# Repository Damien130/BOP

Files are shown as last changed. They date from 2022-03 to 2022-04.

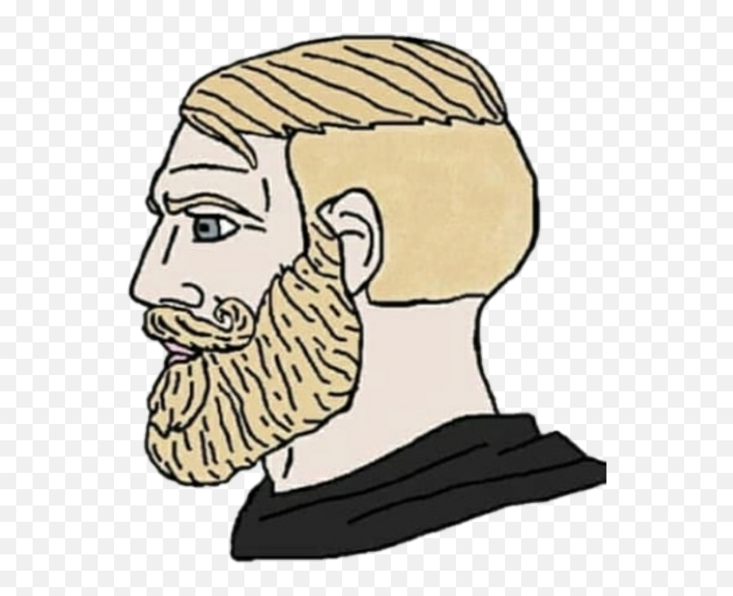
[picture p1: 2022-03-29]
pcb/Chad.png

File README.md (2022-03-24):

	Welcome to Chad
	Brought to you by
	ECE1895
⠀⠀⠘⡀⠀⠀⠀⠀⠀⠀⠀⠀⠀⠀⠀⠀⠀⠀⠀⠀⠀⠀⠀⠀⠀⠀⡜⠀⠀⠀
⠀⠀⠀⠑⡀⠀⠀⠀⠀⠀⠀⠀⠀⠀⠀⠀⠀⠀⠀⠀⠀⠀⠀⠀⠀⡔⠁⠀⠀⠀
⠀⠀⠀⠀⠈⠢⢄⠀⠀⠀⠀⠀⠀⠀⠀⠀⠀⠀⠀⠀⠀⠀⣀⠴⠊⠀⠀⠀⠀⠀
⠀⠀⠀⠀⠀⠀⠀⢸⠀⠀⠀⢀⣀⣀⣀⣀⣀⡀⠤⠄⠒⠈⠀⠀⠀⠀⠀⠀⠀⠀
⠀⠀⠀⠀⠀⠀⠀⠘⣀⠄⠊⠁⠀⠀⠀⠀⠀⠀⠀⠀⠀⠀⠀⠀⠀⠀⠀⠀⠀⠀
⠀
⣿⣿⣿⣿⣿⣿⣿⣿⡿⠿⠛⠛⠛⠋⠉⠈⠉⠉⠉⠉⠛⠻⢿⣿⣿⣿⣿⣿⣿⣿
⣿⣿⣿⣿⣿⡿⠋⠁⠀⠀⠀⠀⠀⠀⠀⠀⠀⠀⠀⠀⠀⠀⠀⠉⠛⢿⣿⣿⣿⣿
⣿⣿⣿⣿⡏⣀⠀⠀⠀⠀⠀⠀⠀⣀⣤⣤⣤⣄⡀⠀⠀⠀⠀⠀⠀⠀⠙⢿⣿⣿
⣿⣿⣿⢏⣴⣿⣷⠀⠀⠀⠀⠀⢾⣿⣿⣿⣿⣿⣿⡆⠀⠀⠀⠀⠀⠀⠀⠈⣿⣿
⣿⣿⣟⣾⣿⡟⠁⠀⠀⠀⠀⠀⢀⣾⣿⣿⣿⣿⣿⣷⢢⠀⠀⠀⠀⠀⠀⠀⢸⣿
⣿⣿⣿⣿⣟⠀⡴⠄⠀⠀⠀⠀⠀⠀⠙⠻⣿⣿⣿⣿⣷⣄⠀⠀⠀⠀⠀⠀⠀⣿
⣿⣿⣿⠟⠻⠀⠀⠀⠀⠀⠀⠀⠀⠀⠀⠶⢴⣿⣿⣿⣿⣿⣧⠀⠀⠀⠀⠀⠀⣿
⣿⣁⡀⠀⠀⢰⢠⣦⠀⠀⠀⠀⠀⠀⠀⠀⢀⣼⣿⣿⣿⣿⣿⡄⠀⣴⣶⣿⡄⣿
⣿⡋⠀⠀⠀⠎⢸⣿⡆⠀⠀⠀⠀⠀⠀⣴⣿⣿⣿⣿⣿⣿⣿⠗⢘⣿⣟⠛⠿⣼
⣿⣿⠋⢀⡌⢰⣿⡿⢿⡀⠀⠀⠀⠀⠀⠙⠿⣿⣿⣿⣿⣿⡇⠀⢸⣿⣿⣧⢀⣼
⣿⣿⣷⢻⠄⠘⠛⠋⠛⠃⠀⠀⠀⠀⠀⢿⣧⠈⠉⠙⠛⠋⠀⠀⠀⣿⣿⣿⣿⣿
⣿⣿⣧⠀⠈⢸⠀⠀⠀⠀⠀⠀⠀⠀⠀⠀⠟⠀⠀⠀⠀⢀⢃⠀⠀⢸⣿⣿⣿⣿
⣿⣿⡿⠀⠴⢗⣠⣤⣴⡶⠶⠖⠀⠀⠀⠀⠀⠀⠀⠀⠀⠀⠀⣀⡸⠀⣿⣿⣿⣿
⣿⣿⣿⡀⢠⣾⣿⠏⠀⠠⠀⠀⠀⠀⠀⠀⠀⠀⠀⠀⠀⠀⠀⠛⠉⠀⣿⣿⣿⣿
⣿⣿⣿⣧⠈⢹⡇⠀⠀⠀⠀⠀⠀⠀⠀⠀⠀⠀⠀⠀⠀⠀⠀⠀⠀⣰⣿⣿⣿⣿
⣿⣿⣿⣿⡄⠈⠃⠀⠀⠀⠀⠀⠀⠀⠀⠀⠀⠀⠀⠀⠀⢀⣠⣴⣾⣿⣿⣿⣿⣿
⣿⣿⣿⣿⣧⡀⠀⠀⠀⠀⠀⠀⠀⠀⠀⠀⠀⠀⢀⣠⣾⣿⣿⣿⣿⣿⣿⣿⣿⣿
⣿⣿⣿⣿⣷⠀⠀⠀⠀⠀⠀⠀⠀⠀⠀⠀⢀⣴⣿⣿⣿⣿⣿⣿⣿⣿⣿⣿⣿⣿
⣿⣿⣿⣿⣿⣦⣄⣀⣀⣀⣀⠀⠀⠀⠀⠘⣿⣿⣿⣿⣿⣿⣿⣿⣿⣿⣿⣿⣿⣿
⣿⣿⣿⣿⣿⣿⣿⣿⣿⣿⣿⣷⡄⠀⠀⠀⣿⣿⣿⣿⣿⣿⣿⣿⣿⣿⣿⣿⣿⣿
⣿⣿⣿⣿⣿⣿⣿⣿⣿⣿⣿⣿⣧⠀⠀⠀⠙⣿⣿⡟⢻⣿⣿⣿⣿⣿⣿⣿⣿⣿
⣿⣿⣿⣿⣿⣿⣿⣿⣿⣿⣿⣿⠇⠀⠁⠀⠀⠹⣿⠃⠀⣿⣿⣿⣿⣿⣿⣿⣿⣿
⣿⣿⣿⣿⣿⣿⣿⣿⡿⠛⣿⣿⠀⠀⠀⠀⠀⠀⠀⠀⢐⣿⣿⣿⣿⣿⣿⣿⣿⣿
⣿⣿⣿⣿⠿⠛⠉⠉⠁⠀⢻⣿⡇⠀⠀⠀⠀⠀⠀⢀⠈⣿⣿⡿⠉⠛⠛⠛⠉⠉
⣿⡿⠋⠁⠀⠀⢀⣀⣠⡴⣸⣿⣇⡄⠀⠀⠀⠀⢀⡿⠄⠙⠛⠀⣀⣠⣤⣤⠄

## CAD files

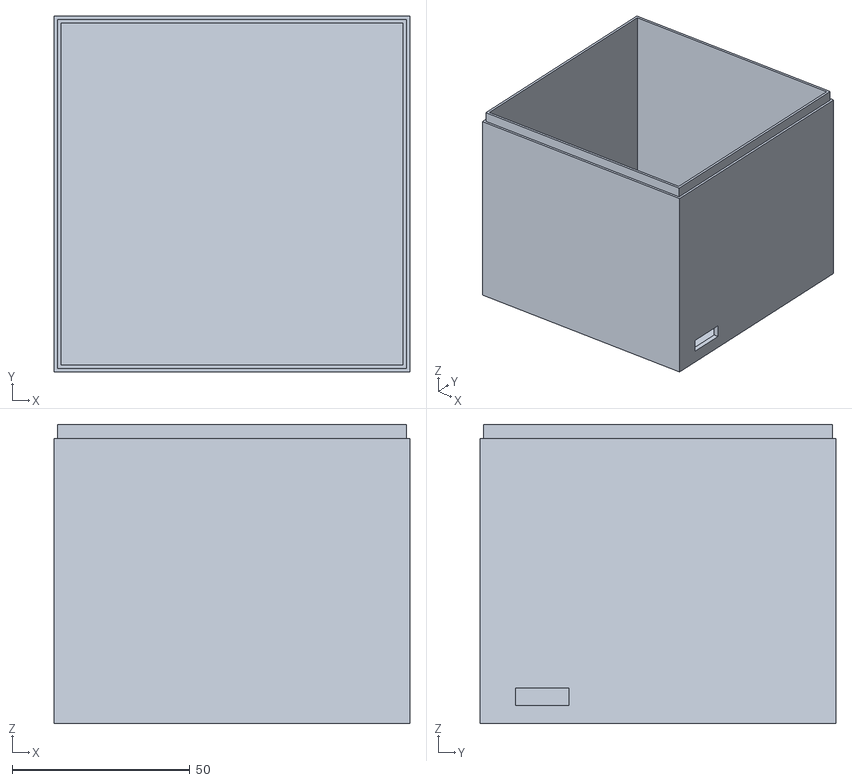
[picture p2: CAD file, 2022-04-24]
enclosure/Bop-it3 Box.stl
100.0 x 100.0 x 84.0

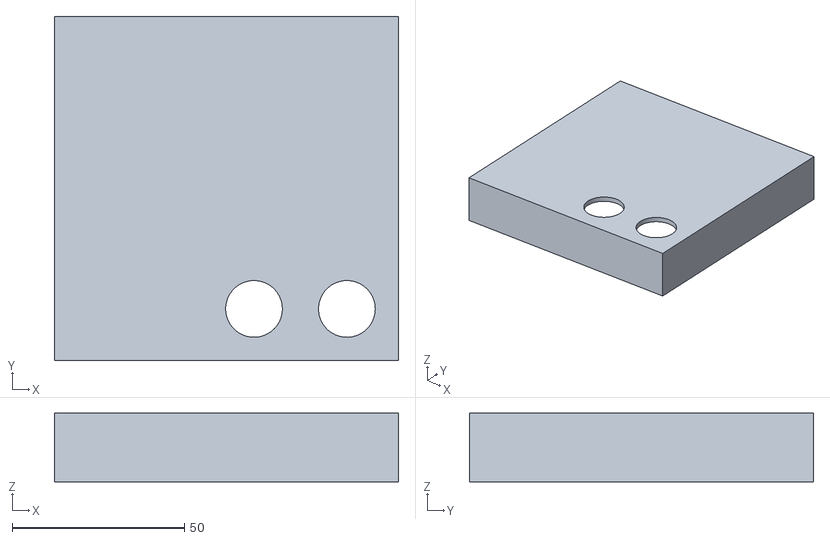
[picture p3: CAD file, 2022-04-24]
enclosure/Bop-it3 Lid.stl
100.0 x 100.0 x 20.0

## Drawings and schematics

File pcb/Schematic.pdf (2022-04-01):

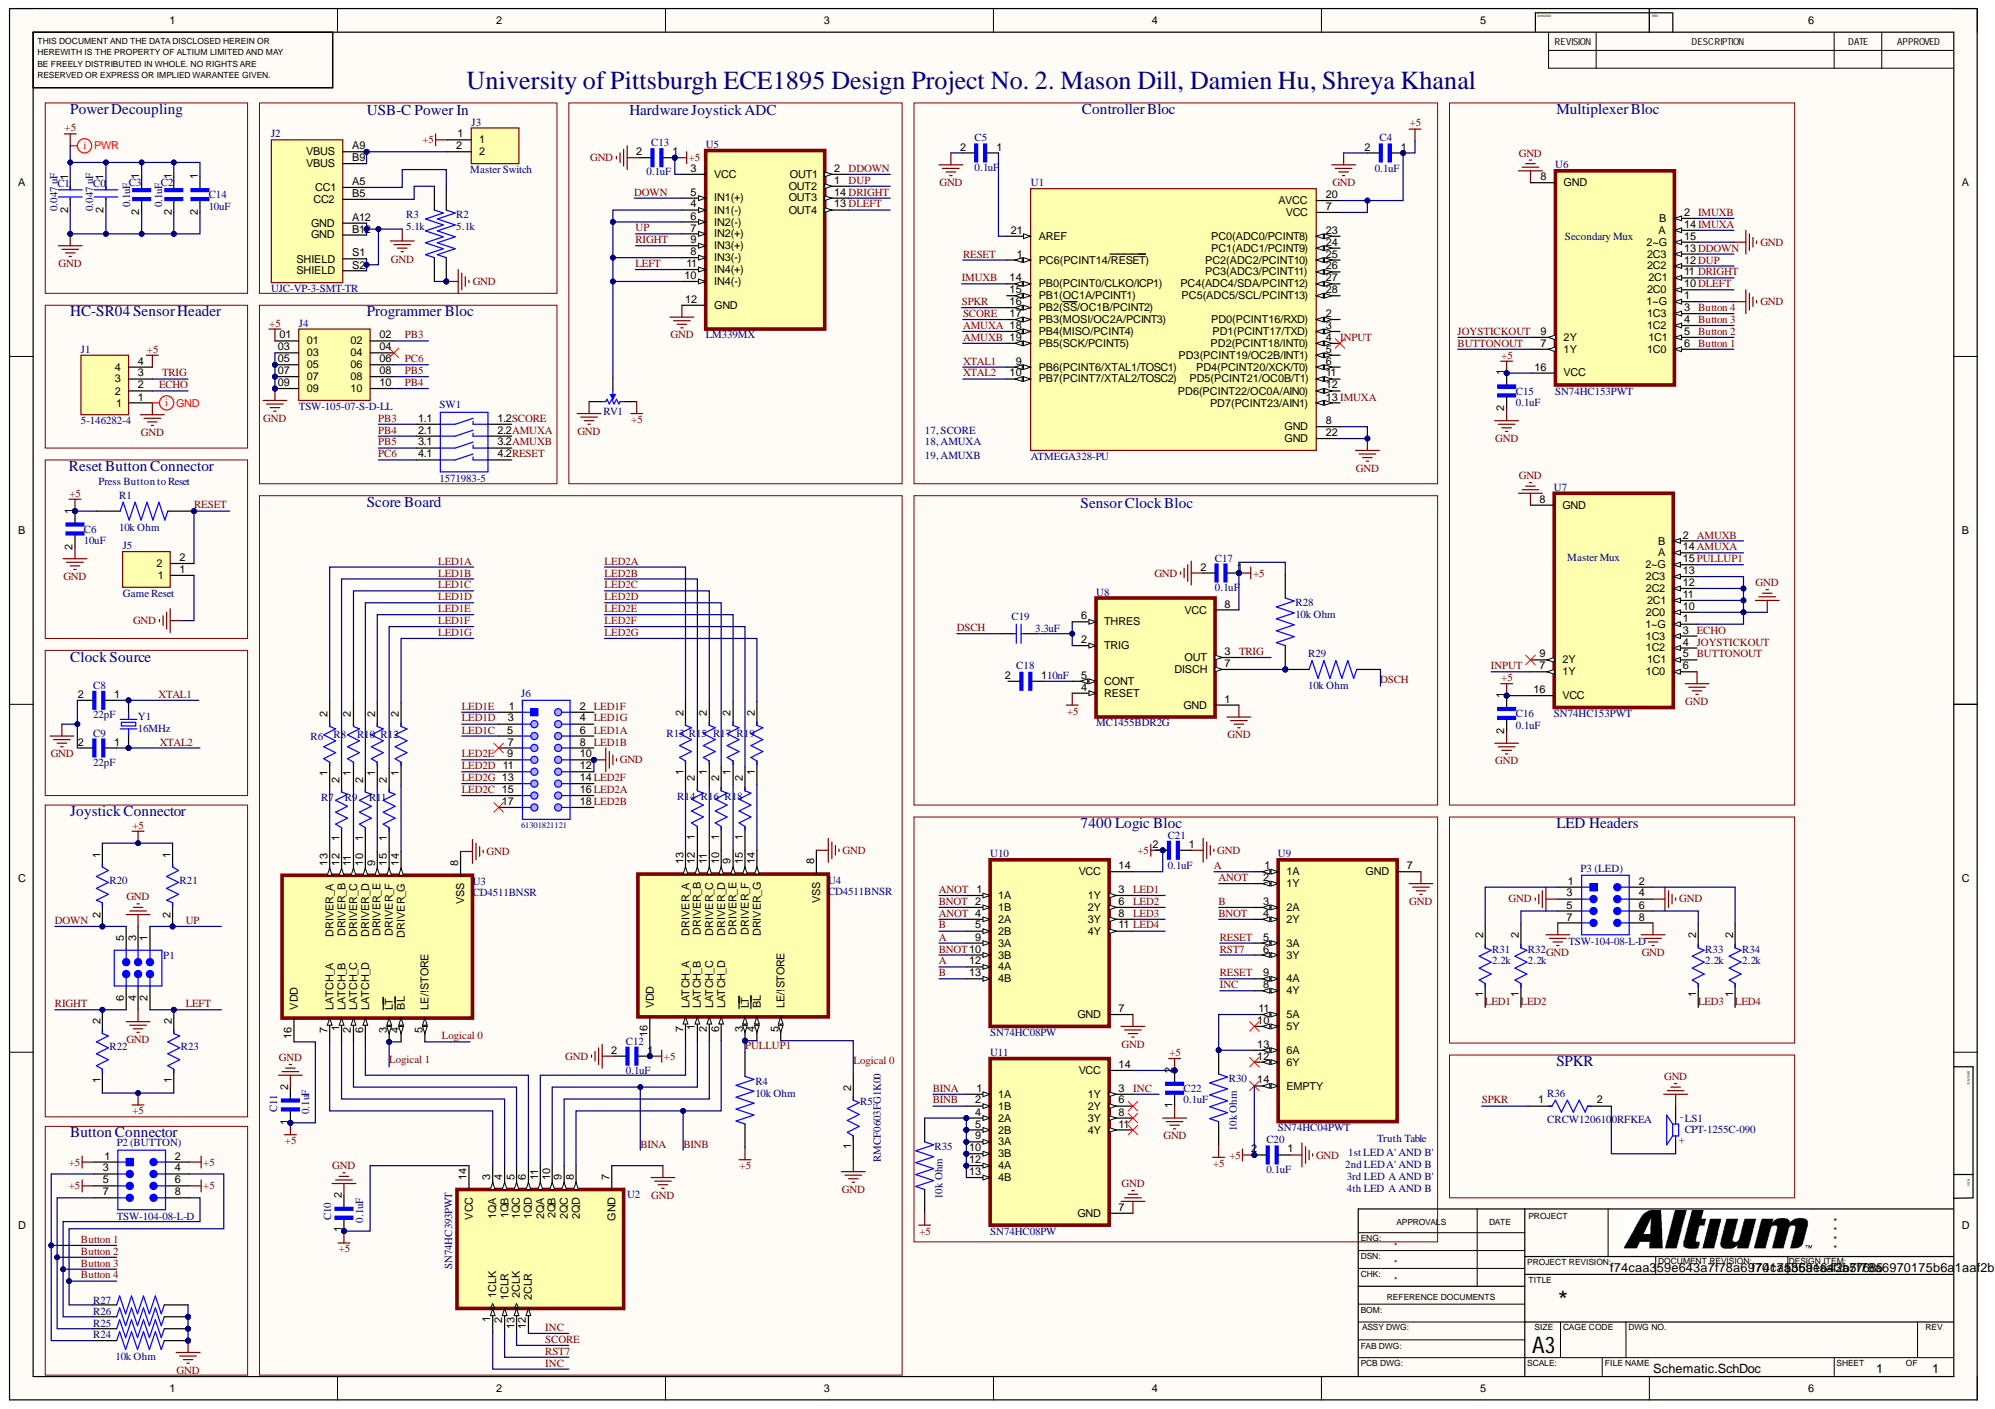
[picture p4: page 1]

1 | 2 | 3 | 4 | 5 | DWG NO: | REV: | 6

THIS DOCUMENT AND THE DATA DISCLOSED HEREIN OR HEREWITH IS THE PROPERTY OF ALTIUM LIMITED AND MAY BE FREELY DISTRIBUTED IN WHOLE. NO RIGHTS ARE RESERVED OR EXPRESS OR IMPLIED WARANTEE GIVEN. | | REVISION | DESCRIPTION | DATE | APPROVED

University of Pittsburgh ECE1895 Design Project No. 2. Mason Dill, Damien Hu, Shreya Khanal

UJC-VP-3-SMT-TR

Reset Button Connector
Press Button to Reset

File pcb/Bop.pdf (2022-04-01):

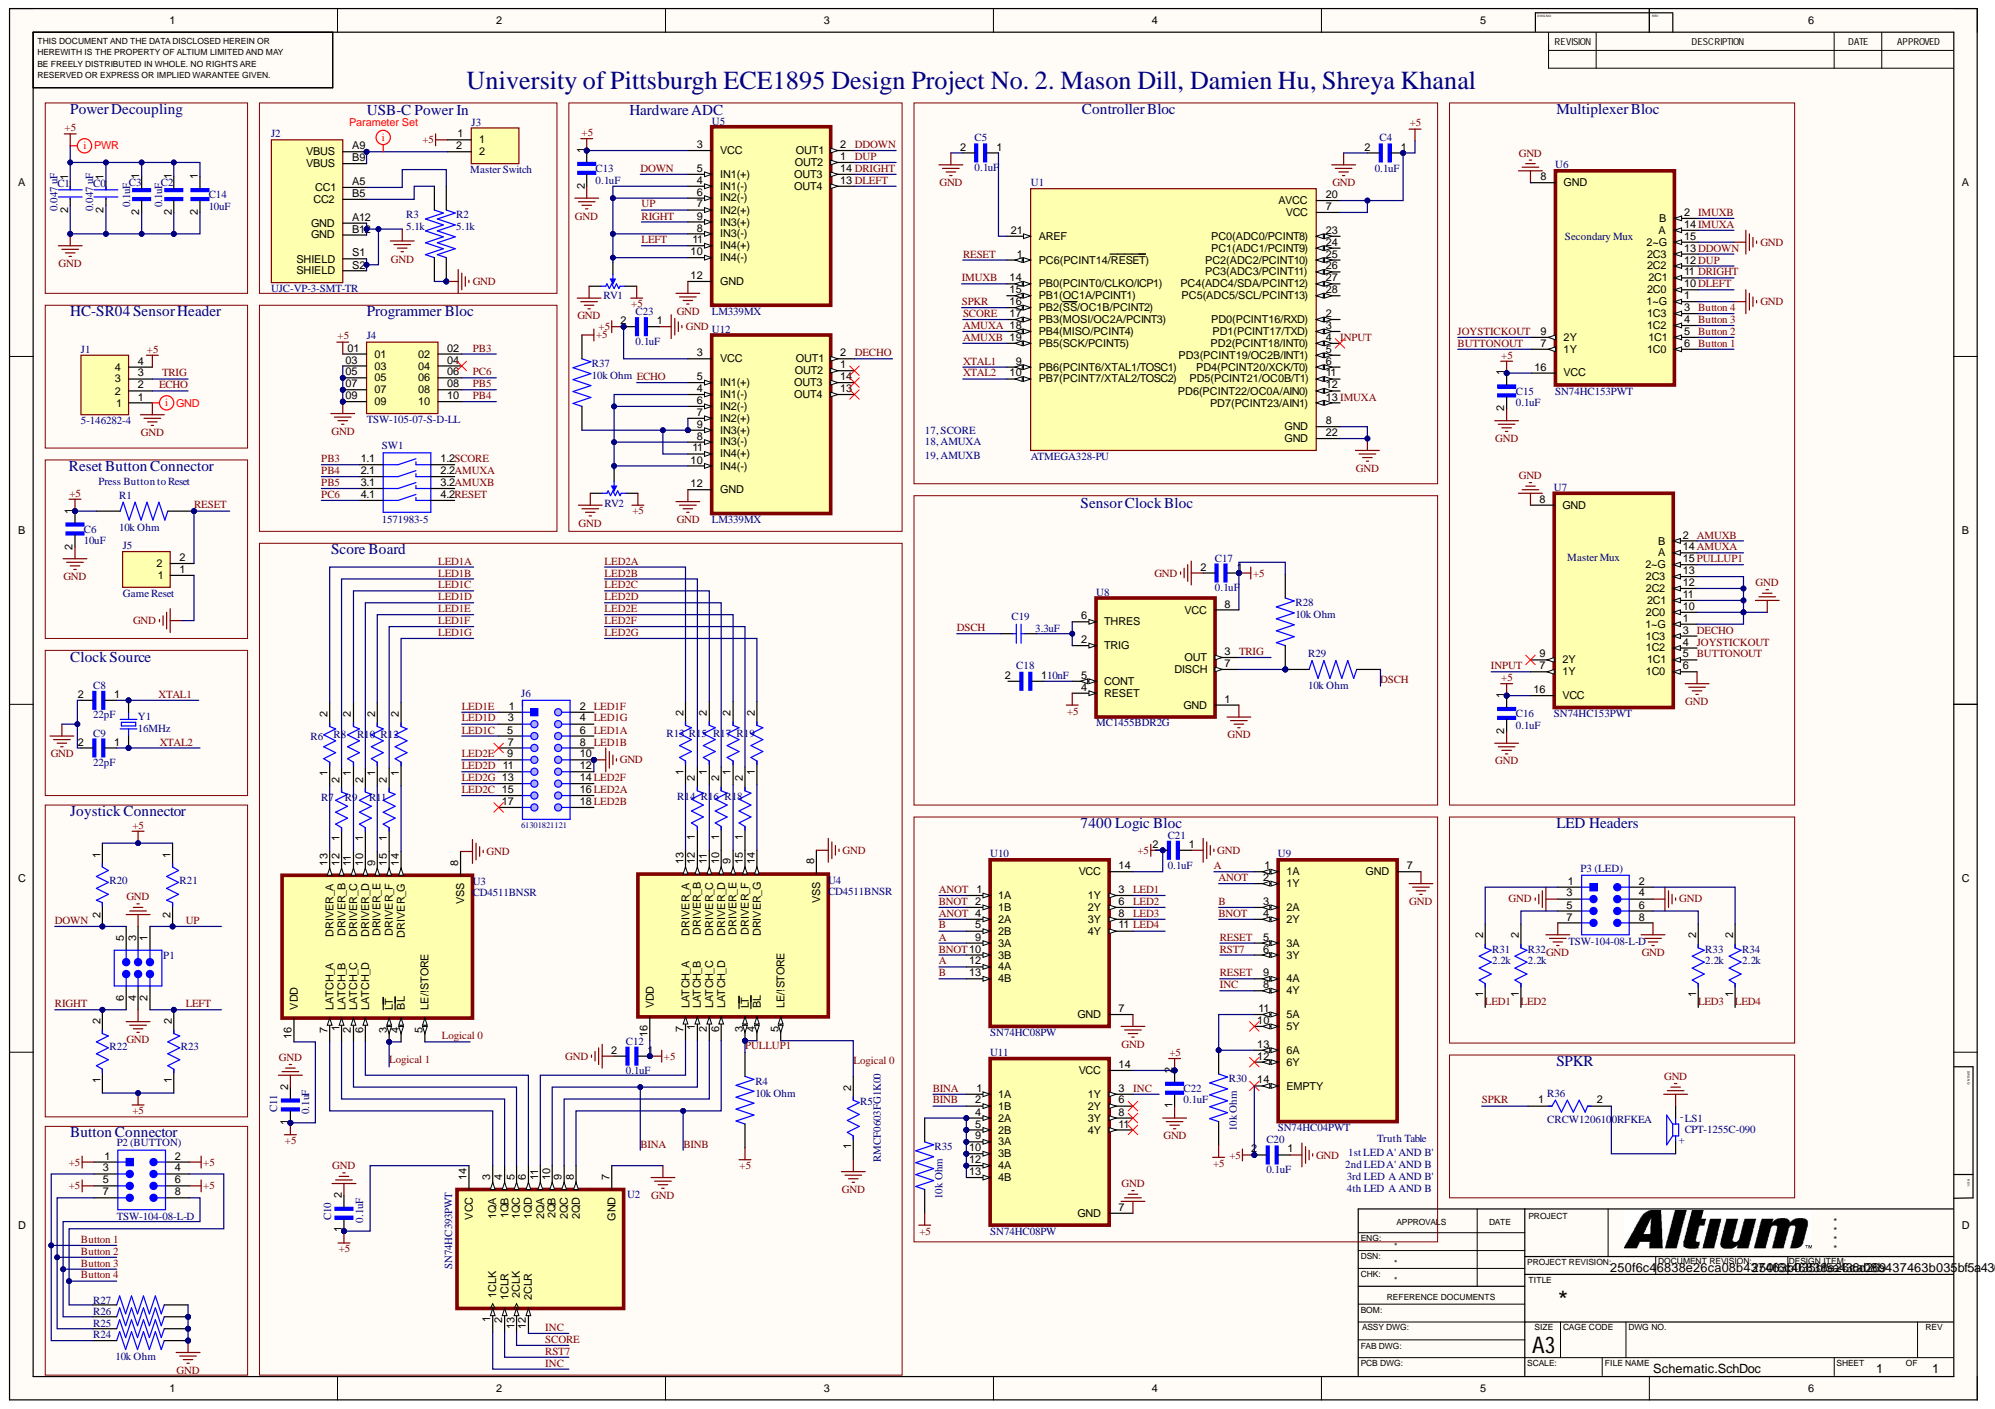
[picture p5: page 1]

1 | 2 | 3 | 4 | 5 | DWG NO: | REV: | 6

THIS DOCUMENT AND THE DATA DISCLOSED HEREIN OR HEREWITH IS THE PROPERTY OF ALTIUM LIMITED AND MAY BE FREELY DISTRIBUTED IN WHOLE. NO RIGHTS ARE RESERVED OR EXPRESS OR IMPLIED WARANTEE GIVEN. | | REVISION | DESCRIPTION | DATE | APPROVED

University of Pittsburgh ECE1895 Design Project No. 2. Mason Dill, Damien Hu, Shreya Khanal

UJC-VP-3-SMT-TR

Reset Button Connector
Press Button to Reset

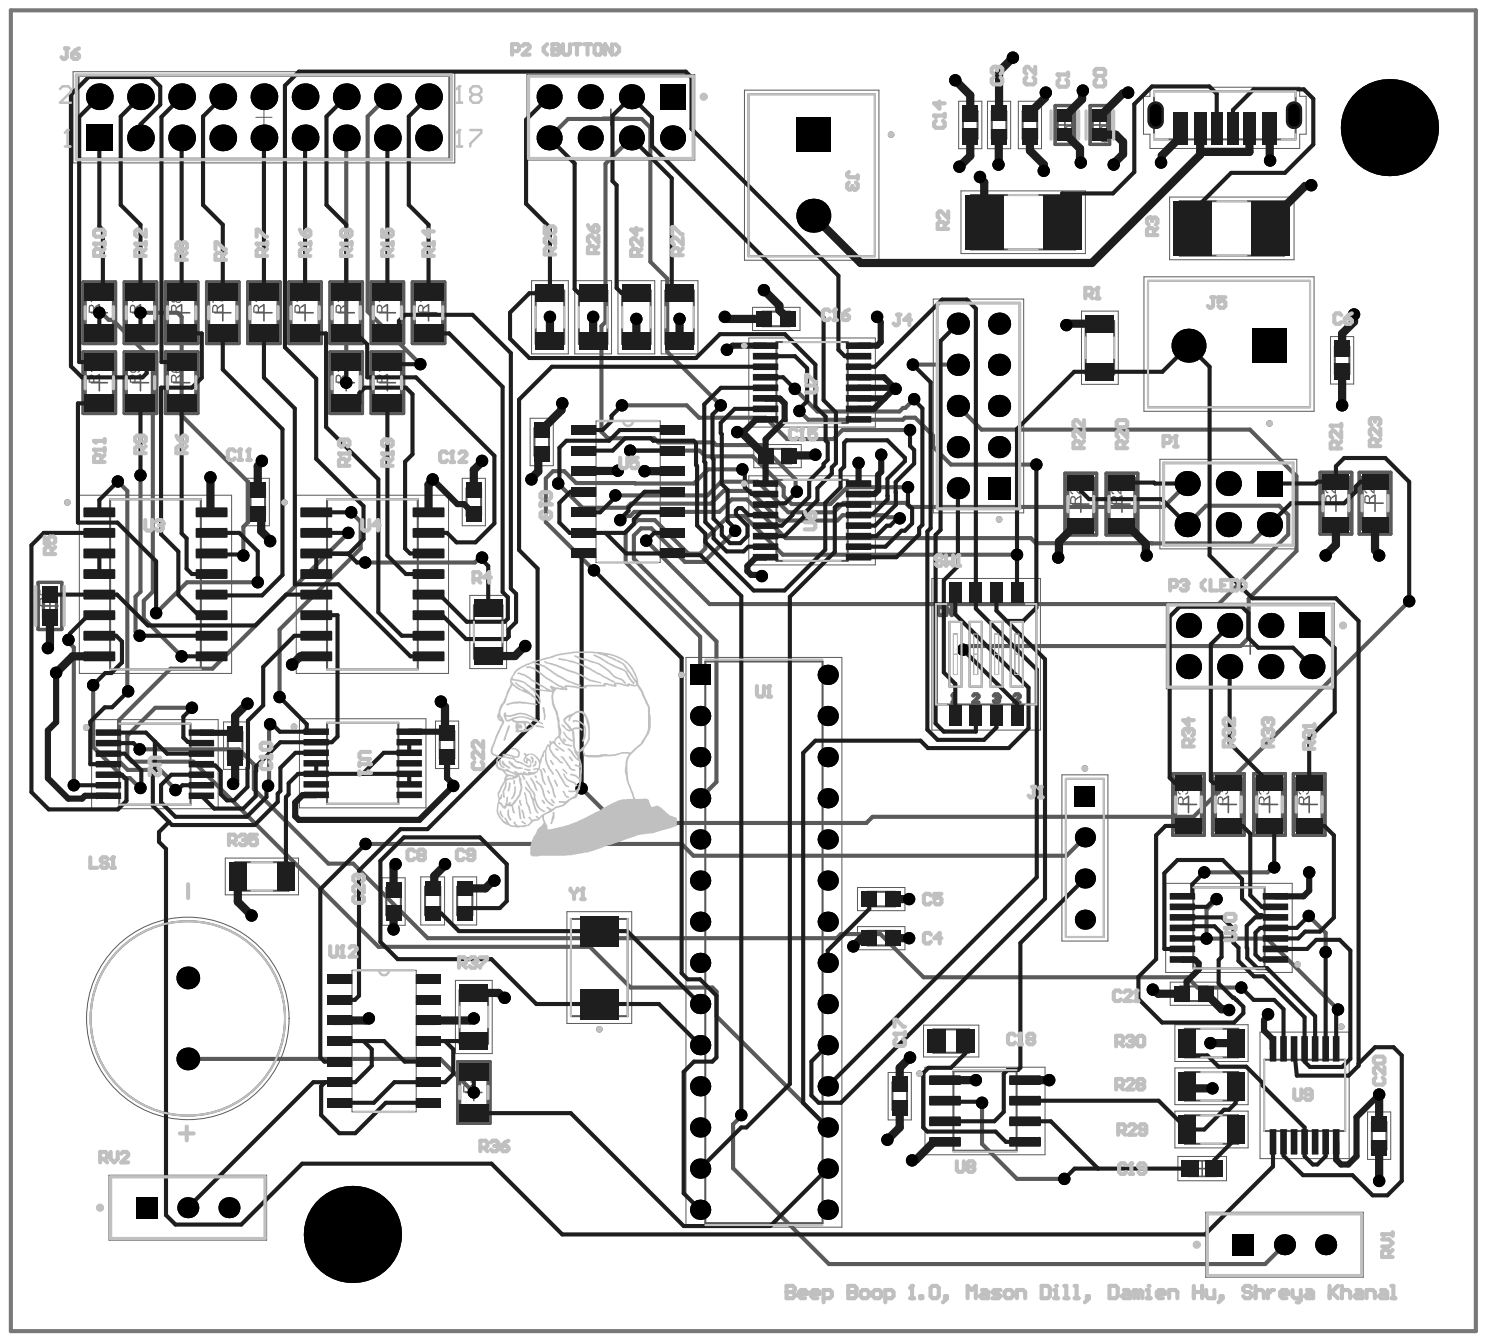
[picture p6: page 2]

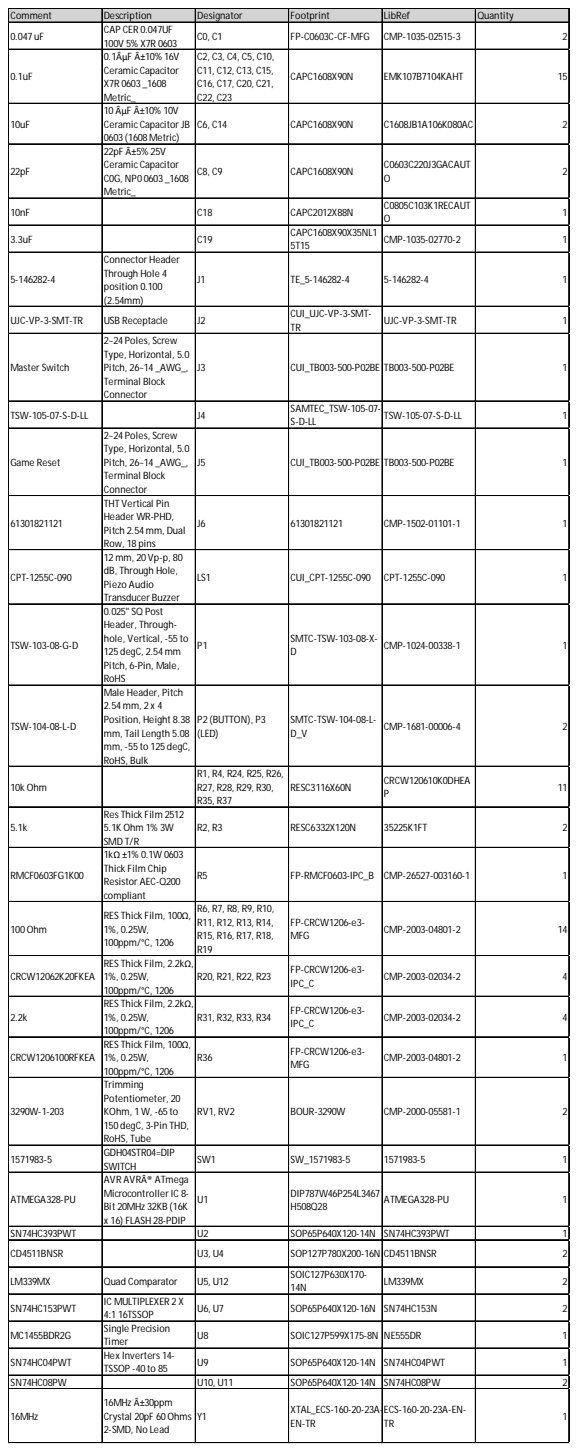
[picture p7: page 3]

Comment | Description | Designator | Footprint | LibRef | Quantity
0.047 uF | CAP CER 0.047UF 100V 5% X7R 0603 | C0, C1 | FP-C0603C-CF-MFG | CMP-1035-02515-3 | 2

0.1uF | 0.1ÂµF Â±10% 16V Ceramic Capacitor X7R 0603 _1608 Metric_ | C2, C3, C4, C5, C10, C11, C12, C13, C15, C16, C17, C20, C21, C22, C23 | CAPC1608X90N | EMK107B7104KAHT | 15

10uF | 10 ÂµF Â±10% 10V Ceramic Capacitor JB 0603 (1608 Metric) | C6, C14 | CAPC1608X90N | C1608JB1A106K080AC | 2

22pF | 22pF Â±5% 25V Ceramic Capacitor C0G, NP0 0603 _1608 Metric_ | C8, C9 | CAPC1608X90N | C0603C220J3GACAUT O | 2

10nF | | C18 | CAPC2012X88N | C0805C103K1RECAUT O | 1

3.3uF | | C19 | CAPC1608X90X35NL1 5T15 | CMP-1035-02770-2 | 1

5-146282-4 | Connector Header Through Hole 4 position 0.100 (2.54mm) | J1 | TE_5-146282-4 | 5-146282-4 | 1

UJC-VP-3-SMT-TR | USB Receptacle | J2 | CUI_UJC-VP-3-SMT-TR | UJC-VP-3-SMT-TR | 1

Master Switch | 2~24 Poles, Screw Type, Horizontal, 5.0 Pitch, 26~14 _AWG_, Terminal Block Connector | J3 | CUI_TB003-500-P02BE | TB003-500-P02BE | 1

TSW-105-07-S-D-LL | | J4 | SAMTEC_TSW-105-07-S-D-LL | TSW-105-07-S-D-LL | 1

Game Reset | 2~24 Poles, Screw Type, Horizontal, 5.0 Pitch, 26~14 _AWG_, Terminal Block Connector | J5 | CUI_TB003-500-P02BE | TB003-500-P02BE | 1

61301821121 | THT Vertical Pin Header WR-PHD, Pitch 2.54mm, Dual Row, 18 pins | J6 | 61301821121 | CMP-1502-01101-1 | 1

CPT-1255C-090 | 12mm, 20 Vp-p, 80 dB, Through Hole, Piezo Audio Transducer Buzzer | LS1 | CUI_CPT-1255C-090 | CPT-1255C-090 | 1

TSW-103-08-G-D | 0.025" SQ Post Header, Through-hole, Vertical, -55 to 125 degC, 2.54mm Pitch, 6-Pin, Male, RoHS | P1 | SMTC-TSW-103-08-X-D | CMP-1024-00338-1 | 1

TSW-104-08-L-D | Male Header, Pitch 2.54mm, 2 x 4 Position, Height 8.38 mm, Tail Length 5.08 mm, -55 to 125 degC, RoHS, Bulk | P2 (BUTTON), P3 (LED) | SMTC-TSW-104-08-L-D_V | CMP-1681-00006-4 | 2

10k Ohm | | R1, R4, R24, R25, R26, R27, R28, R29, R30, R35, R37 | RESC3116X60N | CRCW120610K0DHEA P | 11

5.1k | Res Thick Film 2512 5.1K Ohm 1% 3W SMD T/R | R2, R3 | RESC6332X120N | 35225K1FT | 2

RMCF0603FG1K00 | 1kΩ ±1% 0.1W 0603 Thick Film Chip Resistor AEC-Q200 compliant | R5 | FP-RMCF0603-IPC_B | CMP-26527-003160-1 | 1

100Ohm | RES Thick Film, 100Ω, 1%, 0.25W, 100ppm/°C, 1206 | R6, R7, R8, R9, R10, R11, R12, R13, R14, R15, R16, R17, R18, R19 | FP-CRCW1206-e3-MFG | CMP-2003-04801-2 | 14

CRCW12062K20FKEA | RES Thick Film, 2.2kΩ, 1%, 0.25W, 100ppm/°C, 1206 | R20, R21, R22, R23 | FP-CRCW1206-e3-IPC_C | CMP-2003-02034-2 | 4

2.2k | RES Thick Film, 2.2kΩ, 1%, 0.25W, 100ppm/°C, 1206 | R31, R32, R33, R34 | FP-CRCW1206-e3-IPC_C | CMP-2003-02034-2 | 4

CRCW1206100RFKEA | RES Thick Film, 100Ω, 1%, 0.25W, 100ppm/°C, 1206 | R36 | FP-CRCW1206-e3-MFG | CMP-2003-04801-2 | 1

3290W-1-203 | Trimming Potentiometer, 20 KOhm, 1 W, -65 to 150 degC, 3-Pin THD, RoHS, Tube | RV1, RV2 | BOUR-3290W | CMP-2000-05581-1 | 2

1571983-5 | GDH04STR04=DIP SWITCH | SW1 | SW_1571983-5 | 1571983-5 | 1

ATMEGA328-PU | AVR AVRÂ® ATmega Microcontroller IC 8-Bit 20MHz 32KB (16K x 16) FLASH 28-PDIP | U1 | DIP787W46P254L3467 H508Q28 | ATMEGA328-PU | 1

SN74HC393PWT | | U2 | SOP65P640X120-14N | SN74HC393PWT | 1

CD4511BNSR | | U3, U4 | SOP127P780X200-16N | CD4511BNSR | 2

LM339MX | Quad Comparator | U5, U12 | SOIC127P630X170-14N | LM339MX | 2

SN74HC153PWT | IC MULTIPLEXER 2 X 4:1 16TSSOP | U6, U7 | SOP65P640X120-16N | SN74HC153N | 2

MC1455BDR2G | Single Precision Timer | U8 | SOIC127P599X175-8N | NE555DR | 1

SN74HC04PWT | Hex Inverters 14-TSSOP -40 to 85 | U9 | SOP65P640X120-14N | SN74HC04PWT | 1

SN74HC08PW | | U10, U11 | SOP65P640X120-14N | SN74HC08PW | 2

16MHz | 16MHz Â±30ppm Crystal 20pF 60Ohms 2-SMD, No Lead | Y1 | XTAL_ECS-160-20-23A-EN-TR | ECS-160-20-23A-EN-TR | 1

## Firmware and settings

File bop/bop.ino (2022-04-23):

//Mason Dill
//Using libraries time and time alarm

unsigned long c_time;
unsigned long last_c_time;
volatile byte state = HIGH;

unsigned int roundTime;

unsigned int playerScore;
bool gameOver;

enum devices {BUTTONS, STICK, SONIC};
enum color {RED, GREEN, BLUE, YELLOW};

//prototypes
void muxByColor(enum color num, int pin);
void muxByDevice(enum devices d, int pin);
void score();

void setdown();

void setup() {
  interrupts();
  pinMode(2, INPUT); //intterupt pin                PHYSICAL PIN 4
  attachInterrupt(digitalPinToInterrupt(2), score, HIGH);
  
  pinMode(7, OUTPUT); //color mux                   PHYSICAL PIN 13
  pinMode(8, OUTPUT); //AKA secondary Mux           PHYSICAL PIN 14

  pinMode(12, OUTPUT); //device mux                 PHYSICAL PIN 18
  pinMode(13, OUTPUT); //AKA Master mux             PHYSICAL PIN 19

  pinMode(11, OUTPUT); //Notify BCD to increment    PHYSICAL PIN 17
  pinMode(10, OUTPUT); //speaker sound signal       PHYSICAL PIN 16
  
  //randomSeed(analogRead(0)); //generate random seed from noise

  c_time = 0;
  last_c_time = millis();
  roundTime  = 4000;
  playerScore = 0;
  gameOver = false;
}

void score(){
  //check to see if addToScore() was called in the last 250 milliseconds
  if (last_c_time < c_time){
    state = LOW;
    digitalWrite(11, LOW); //this will increment the BCD; adds 1 to score display
    playerScore++;
    last_c_time = millis();
   }
   if(playerScore < 100)
    gameOver = false;
}

void loop() {
  if(gameOver){
    //disconnect interrupt pin from all input devices
    digitalWrite(12, LOW);
    digitalWrite(13, LOW);
    
    //Game will become stuck in this loop if addToScore is not called at the end of this function 
    return;
  }
  gameOver = true;
  //select a random device
  enum devices curD = (enum devices)random(3);
  
  //select a random color 
  enum color curC = (enum color)random(0, 4);;

  muxByColor(curC, 7);//display color to user, mux by interaction
  muxByDevice(curD, 12);//mux by device
  playSound(curD, 16);
   
   c_time = millis();
   delay(roundTime);

   //minimum round time = 500 ms
   if(roundTime > 500)
      roundTime -= 50;
   digitalWrite(11, HIGH);
}

void playSound(enum devices d, int pin){
  switch(d){
    case BUTTONS: analogWrite(pin, 100);
      break;
    case STICK: analogWrite(pin, 170);
      break;
    case SONIC: analogWrite(pin, 250);
      break;
  }
}

void muxByColor(enum color num, int pin){
  switch(num){
    case RED: 
    digitalWrite(pin, LOW);
    digitalWrite(pin+1, LOW);
    break;
    case GREEN:
    digitalWrite(pin, HIGH);
    digitalWrite(pin+1, LOW);
    break;
    case BLUE:
    digitalWrite(pin, LOW);
    digitalWrite(pin+1, HIGH);
    break;
    case YELLOW:
    digitalWrite(pin, HIGH);
    digitalWrite(pin+1, HIGH);
  }
}

void muxByDevice(enum devices d, int pin){
  if (d == BUTTONS){
      digitalWrite(pin, HIGH);
      digitalWrite(pin+1, LOW);
    } else if (d == STICK){
      digitalWrite(pin, LOW);
      digitalWrite(pin+1, HIGH);
    } else if (d == SONIC){
      digitalWrite(pin, HIGH);
      digitalWrite(pin+1, HIGH);
    }
}

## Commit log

2022-03-24 pitch/color randomization
2022-03-26 Timing and interrupts
2022-03-28 added PCB
    [Bop.PrjPcb, PCB.PcbDoc, Schematic.SchDoc]
2022-03-28 Updated 7-Seg Circuitry
    [Schematic.SchDoc]
2022-03-29 Joystick and new decoupling mechanism
    [Schematic.SchDoc]
2022-03-29 Button Connector and logic
    [Schematic.SchDoc]
2022-03-29 Schematic Complete except I/O connection
    [Schematic.SchDoc]
2022-03-29 Finalizing logic circuitry
    [Bop.PrjPcb, PCB.PcbDoc, Schematic.SchDoc]
2022-03-29 Beep Boop 1.0
    [Bop.PrjPcb, PCB.PcbDoc, Schematic.SchDoc]
2022-03-29 Need Speaker
    [Bop.PrjPcb, Schematic.SchDoc]
2022-03-31 Added DIP
    [Schematic.SchDoc]
2022-03-31 Revert ""
    This reverts commit 941b0a7538026b0af43b5d36929d1c7ddd8199e5.
    [Bop.PrjPcb]
2022-03-31 added DIP and Speaker
    [Schematic.SchDoc]
2022-04-01 PCB Finalized
    [Bop.PrjPcb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]
2022-04-01 Fixed Drill Files
    [Bop.PrjPcb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]
2022-04-01 Generated .DRL file instead of .TXT Drill Files.
    [Bop.PrjPcb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]
2022-04-24 Added enclosure files
    [Bop-it3 Box.stl, Bop-it3 Lid.stl]
